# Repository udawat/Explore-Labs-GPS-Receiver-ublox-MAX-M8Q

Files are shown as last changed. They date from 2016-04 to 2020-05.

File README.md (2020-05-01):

# Explore Labs GPS Receiver - ublox MAX-M8Q

<p>The Global Positioning System (GPS) is a satellite-based navigation system made up of a network of 24 or more satellites. Explore Labs GPS Receiver is a 72-channel device based on the uBlox 8th generation chipset that captures those signals and provides accurate location and time information. It has an operating voltage of 3.3V to 5.5V, a high quality ceramic patch antenna on board, and connects to your system via TTL serial broken out on 2.54 cm breadboard compatible pads.</p>

<p><strong>Design Features:</strong></p>
<ul>
    <li>Upto 18 Hz update rate for GPS-only mode.</li>
    <li>40 square mm Ground Plane for better antenna gain and directivity.</li>
    <li>External I2C EEPROM for receiver configuration storage</li>
    <li>Backup battery as Supercapacitor for efficient warm start and storage of settings. Currently provides backup time of approx 10 seconds.</li>
    <li>Power Input: 3.3V to 5.5V Input. Or, If connected to an IMU 9 DOF AHRS, may be powered by a Single-cell Lithium Polymer battery.</li>
    <li>1 TTL UART port @ 3.3V. Use a Logic Level converter in between if using a 5V device like an Arduino Uno.</li>
    <li>Power LED - Red and 1PPS Timepulse LED - Blue</li>
    <li>JST-SH six pin horizontal connector - 1.0mm pitch (EM-406, EM-506 compatibile).</li>
    <li>Dimensions: 40 mm x 40 mm x 8.5 mm</li>
    <li>Weight: 16 gram</li>
    <li>Fully assembled and ready to use.</li>
    <li>Supports direct connection with <a title="Explore Labs IMU 9 DOF AHRS With Pressure / Altitude / Humidity / Temperature Sensor" href="https://github.com/udawat/IMU-9DoF-AHRS" target="_blank">Explore Labs IMU 9 DOF AHRS</a>.</li>
    <li>Code library: <a title="Tiny GPS" href="http://github.com/mikalhart/TinyGPS/" target="_blank">TinyGPS</a>.</li>
</ul>

<p><strong>Technical Specifications:</strong></p>
<ul>
    <li>72-channel u-blox M8 engine</li>
    <li>Tracking & Navigation Sensitivity for GPS & GLONASS: –167 dBm</li>
    <li>Horizontal position accuracy: 2.5m CEP</li>
    <li>Time-To-First-Fix for GPS & GLONASS (Cold Start) : 26s (Open Sky)</li>
    <li>Maximum Navigation Update Rate:
        <ul>
            <li>For GPS & GLONASS: 10Hz</li>
            <li>For GPS only: 18Hz</li>
        </ul>
    </li>
</ul>

<p><strong>Applications:</strong></p>
<ul>
    <li>Can be used in UAVs or Hot Air Balloon (HAB) projects.</li>
    <li>Can be used for evaluating the ublox MAX positioning module.</li>
    <li>Vehicle Tracking System and as Fleet Management for Logistics.</li>
    <li>Geocaching - Treasure Hunt.</li>
</ul>

<p><strong>Documents:</strong></p>
<ul>
    <li>Data Sheet: <a title="u-blox MAX-M8" href="https://www.u-blox.com/sites/default/files/MAX-M8_DataSheet_%28UBX-13004644%29.pdf" target="_blank">u-blox MAX-M8</a></li>
</ul>

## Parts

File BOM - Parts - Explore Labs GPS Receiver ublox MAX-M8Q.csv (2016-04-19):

Part | Value | Device | Package | Description | DATASHEET | LINK | MFGPN | PROD_ID | VALUE
C1 | 4.7uF | CAP0603-CAP | 0603-CAP | Capacitor
C2 | 4.7uF | CAP0603-CAP | 0603-CAP | Capacitor
C3 | 0.1uF | CAP0603-CAP | 0603-CAP | Capacitor
C4 | 0.1uF | CAP0603-CAP | 0603-CAP | Capacitor
C5-EEPROM | 0.1uF | CAP0603-CAP | 0603-CAP | Capacitor
C6 | 1.0nF | 1.0UF-16V-10%(0402) | 0402-CAP |  |  |  |  | CAP-12417 | 1.0uF
D1 | RB751V40T1G | DIODESOD | SOD-323 | Diode |  |  |  | DIO-09646
JP1 |  | M04PTH | 1X04 | Header 4
L1 | 5.6nH | INDUCTOR0402 | C0402 | Inductors
L2 | BLM15HD102SN1 | BLM15HD102SN1 | 0402-FERRITE | EMIFIL (R) Chip Ferrite Bead for GHz Noise
L3 | BLM15HD102SN1 | BLM15HD102SN1 | 0402-FERRITE | EMIFIL (R) Chip Ferrite Bead for GHz Noise
LED1 | Green | LEDCHIP-LED0603 | CHIP-LED0603 | LED
LED2 | Blue | LEDCHIP-LED0603 | CHIP-LED0603 | LED
LOGO1 | OSHW-LOGOTOP | OSHW-LOGOTOP | OSHW-LOGO-M-TOP | Open Source Hardware Logo This logo indicates the piece of hardware it is found on incorporates a OSHW license and/or adheres to the definition of open source hardware found here: http://freedomdefined.org/OSHW
LOGO2 | OSHW-LOGOBOTTOM | OSHW-LOGOBOTTOM | OSHW-LOGO-M-BOTTOM | Open Source Hardware Logo This logo indicates the piece of hardware it is found on incorporates a OSHW license and/or adheres to the definition of open source hardware found here: http://freedomdefined.org/OSHW
R1 | 0 | RESISTOR0603-RES | 0603-RES | Resistor
R2 | 330R | RESISTOR0603-RES | 0603-RES | Resistor
R3 | DNP | RESISTOR0603-RES | 0603-RES | Resistor
R4 | 0 | RESISTOR0603-RES | 0603-RES | Resistor
R5 | 1K | RESISTOR0603-RES | 0603-RES | Resistor
R6 | 0 | RESISTOR0603-RES | 0603-RES | Resistor
R7 | 330R | RESISTOR0603-RES | 0603-RES | Resistor
STANDOFF1 | STAND-OFF | STAND-OFF | STAND-OFF | #4 Stand Off
STANDOFF2 | STAND-OFF | STAND-OFF | STAND-OFF | #4 Stand Off
STANDOFF3 | STAND-OFF | STAND-OFF | STAND-OFF | #4 Stand Off
STANDOFF4 | STAND-OFF | STAND-OFF | STAND-OFF | #4 Stand Off
U$9 | EXPLORE-LABS-LOGO | EXPLORE-LABS-LOGO | EXPLORE-LABS-LOGO-TOP
U1 | UBLOX-MAX-M8Q | UBLOX-MAX-M8Q | UBLOX-MAX-M8
U2 | FAR-F6KA-1G5754-L4AJ | FAR-F6KA-1G5754-L4AJ | QCS5E
U3 | BGU7007,115 | BGU7007,115 | SOT886
U4 | GP.1575.25.4.A.02 | GP.1575.25.4.A.02 | GP.1575.25.4.A.02 | Taoglas GP.1575.25.4.A.02 4mm thick GPS Patch Antenna, 1575MHz | http://www.taoglas.com/images/product_images/original_images/GP.1575.25.4.A.02%20GPS%20Patch%20Antenna%201575MHz%20190410.pdf | http://www.taoglas.com/antennas/GPS-GLONASS_Antennas/Internal_GPS_-_Passive_Ceramic_Patch_Antennas/ | GP.1575.25.4.A.02
U5 | ADP122AUJZ-3.3 | ADP122AUJZ-3.3 | SOT-23-5
U6 | TPS72218DBVT | TPS72218DBVT | SOT-23-5
U7 | 24AA32AT-I/OT | 24AA32AT-I/OT | SOT-23-5
U8 | EM406 | EM406 | EM406 | EM406 GPS Connector
U9 | PAS311HR-VA6R | PAS311HR-VA6R | PA311

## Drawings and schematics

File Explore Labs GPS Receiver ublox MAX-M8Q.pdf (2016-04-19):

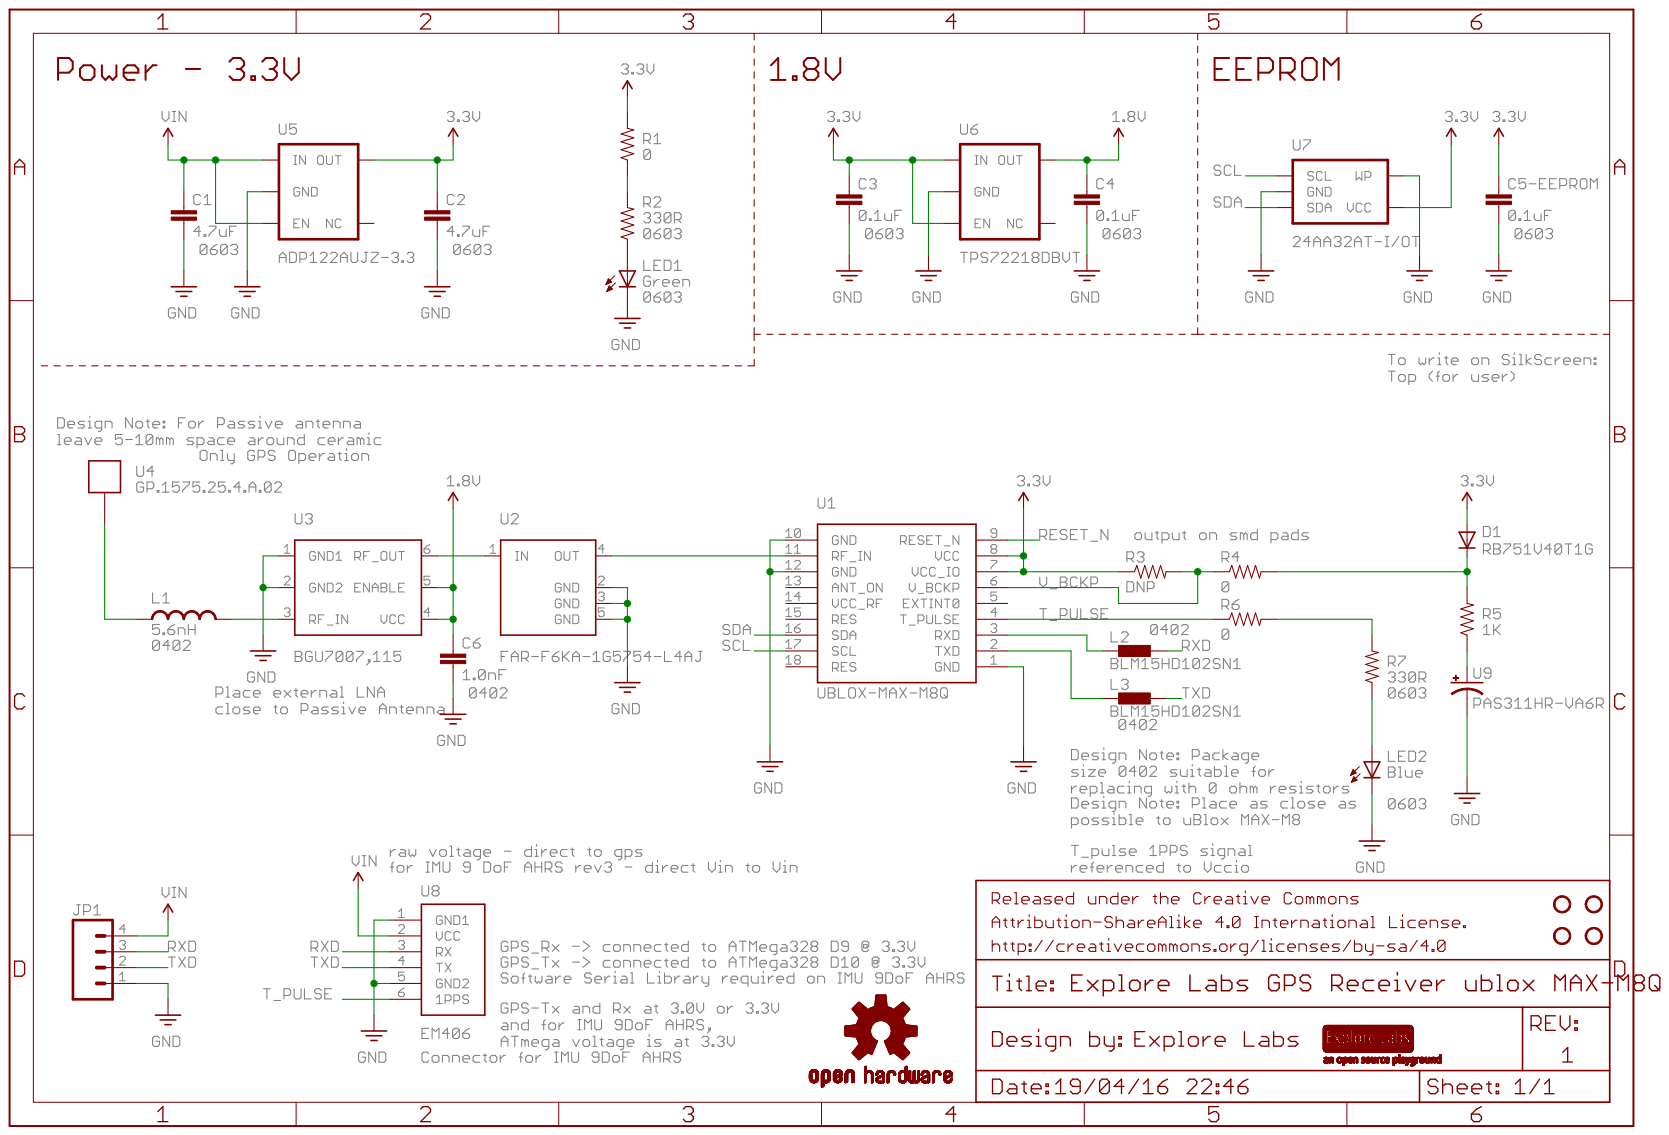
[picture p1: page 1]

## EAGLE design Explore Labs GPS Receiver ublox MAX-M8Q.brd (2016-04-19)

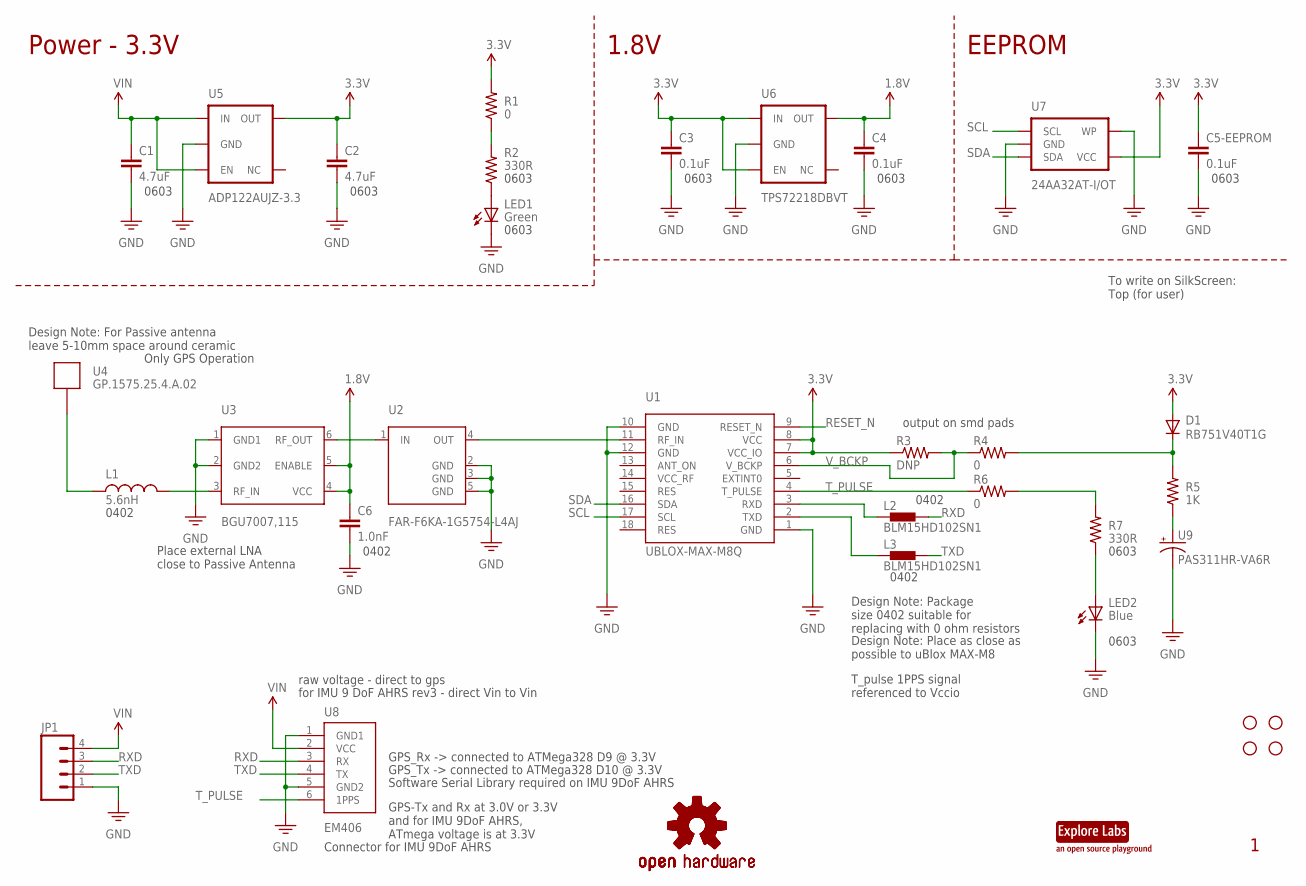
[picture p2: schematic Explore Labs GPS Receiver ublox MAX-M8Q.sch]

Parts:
C1, C2: 4.7uF; 0603-CAP
C3, C4, C5-EEPROM: 0.1uF; 0603-CAP
C6: 1.0nF; 0402-CAP
D1: RB751V40T1G; SOD-323
JP1: M04PTH; 1X04
L1: 5.6nH; C0402
L2, L3: BLM15HD102SN1; 0402-FERRITE
LED1: Green; CHIP-LED0603
LED2: Blue; CHIP-LED0603
LOGO1: OSHW-LOGOTOP; OSHW-LOGO-M-TOP
LOGO2: OSHW-LOGOBOTTOM; OSHW-LOGO-M-BOTTOM
R1, R4, R6: 0; 0603-RES
R2, R7: 330R; 0603-RES
R3: DNP; 0603-RES
R5: 1K; 0603-RES
STANDOFF1, STANDOFF2, STANDOFF3, STANDOFF4: STAND-OFF
U1: UBLOX-MAX-M8Q; UBLOX-MAX-M8
U2: FAR-F6KA-1G5754-L4AJ; QCS5E
U3: BGU7007,115; SOT886
U4: GP.1575.25.4.A.02
U5: ADP122AUJZ-3.3; SOT-23-5
U6: TPS72218DBVT; SOT-23-5
U7: 24AA32AT-I/OT; SOT-23-5
U8: EM406
U9: PAS311HR-VA6R; PA311
U$9: EXPLORE-LABS-LOGO; EXPLORE-LABS-LOGO-TOP

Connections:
1.8V: C4.1, C6.1, U3.4 (VCC), U3.5 (ENABLE), U6.5 (OUT)
3.3V: C2.1, C3.1, C5-EEPROM.1, D1.2 (A), R1.2, R3.1, U1.7 (VCC_IO), U1.8 (VCC), U5.5 (OUT), U6.1 (IN), U6.3 (EN), U7.4 (VCC)
GND: C1.2, C2.2, C3.2, C4.2, C5-EEPROM.2, C6.2, JP1.1, LED1.C, LED2.C, U1.1 (GND), U1.10 (GND), U1.12 (GND), U2.2 (GND), U2.3 (GND), U2.5 (GND), U3.1 (GND1), U3.2 (GND2), U5.2 (GND), U6.2 (GND), U7.2 (GND), U7.5 (WP), U8.1 (GND1), U8.5 (GND2), U9.P$2 (-)
unnamed: U2.1 (IN), U3.6 (RF_OUT)
unnamed: R5.1, U9.P$1 (+)
unnamed: L2.1, U1.3 (RXD)
unnamed: R6.2, R7.2
unnamed: LED2.A, R7.1
unnamed: L3.1, U1.2 (TXD)
unnamed: U1.11 (RF_IN), U2.4 (OUT)
unnamed: D1.1 (C), R4.2, R5.2
unnamed: L1.2, U3.3 (RF_IN)
unnamed: R1.1, R2.2
unnamed: L1.1, U4.1
unnamed: LED1.A, R2.1
RESET_N: U1.9 (RESET_N)
RXD: JP1.3, L2.2, U8.3 (RX)
SCL: U1.17 (SCL), U7.1 (SCL)
SDA: U1.16 (SDA), U7.3 (SDA)
TXD: JP1.2, L3.2, U8.4 (TX)
T_PULSE: R6.1, U1.4 (T_PULSE), U8.6 (1PPS)
VIN: C1.1, JP1.4, U5.1 (IN), U5.3 (EN), U8.2 (VCC)
V_BCKP: R3.2, R4.1, U1.6 (V_BCKP)

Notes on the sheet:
Power - 3.3V
raw voltage - direct to gps
for IMU 9 DoF AHRS rev3 - direct Vin to Vin
Design Note: Place as close as possible to uBlox MAX-M8
Design Note: For Passive antenna leave 5-10mm space around ceramic
GPS-Tx and Rx at 3.0V or 3.3V and for IMU 9DoF AHRS, ATmega voltage is at 3.3V
output on smd pads
Only GPS Operation
Place external LNA close to Passive Antenna
Connector for IMU 9DoF AHRS
GPS_Tx -> connected to ATMega328 D10 @ 3.3V
GPS_Rx -> connected to ATMega328 D9 @ 3.3V
Software Serial Library required on IMU 9DoF AHRS
0603
Design Note: Package size 0402 suitable for replacing with 0 ohm resistors
0402
1.8V
EEPROM
To write on SilkScreen: Top (for user)
T_pulse 1PPS signal referenced to Vccio

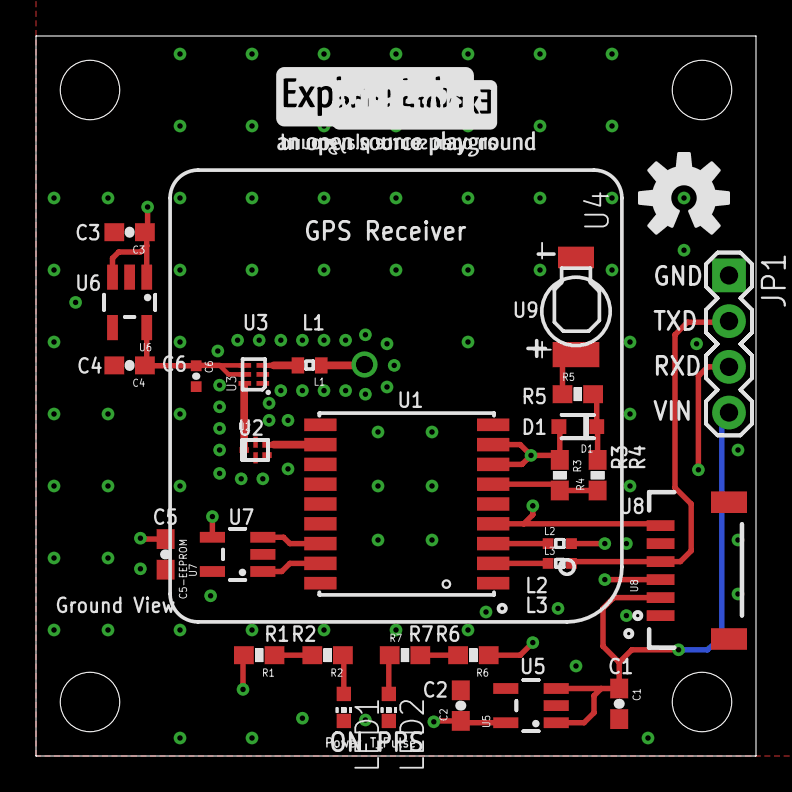
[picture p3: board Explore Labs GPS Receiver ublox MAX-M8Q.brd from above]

Board: 4 copper layers, 40.0 x 40.0 mm, 37 parts (1 on the bottom side), 22 nets.

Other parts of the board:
U$10: EXLABS_LOGO_0.25

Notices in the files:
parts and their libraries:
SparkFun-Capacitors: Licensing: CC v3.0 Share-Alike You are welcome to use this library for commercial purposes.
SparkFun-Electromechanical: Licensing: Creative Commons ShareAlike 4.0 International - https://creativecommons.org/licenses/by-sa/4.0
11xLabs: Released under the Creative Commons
